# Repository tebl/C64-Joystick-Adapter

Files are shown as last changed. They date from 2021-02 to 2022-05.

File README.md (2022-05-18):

# C64 Joystick to USB

As with around 90% of my projects, it all somehow leads back to the Commodore 64 though sometimes even going quite beyond them as well (see [build options](#1-build-options) for these). In this case the idea was to put together a simple adapter so that I could use my Atari-style joysticks, vintage or otherwise, with modern systems over USB (including Raspberry Pi, The64 and the regular ones such as MS Windows 10).

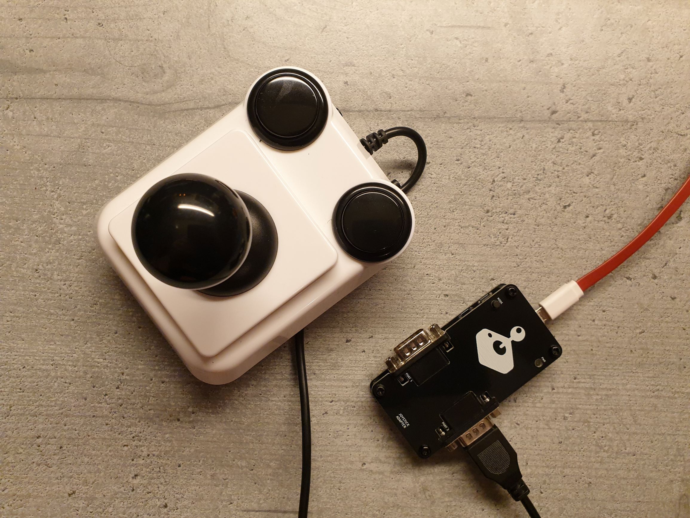
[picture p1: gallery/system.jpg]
System picture


The [JoyConverter](https://github.com/tebl/C64-Joystick-Adapter/tree/main/software/arduino/JoyConverter) firmware also supports paddles, these are mapped to the X and Y position in addition to registering a fire button for each of them (this is because a single port can hold two paddles, so with two ports we could potentially have up to four paddles). This is the mode mentioned in **settings.h**, you can enter paddle mode by holding down the mode button when powering on the unit (hold it down until the LED blinks).

One rather irritating problem with the C64 was that various games expected that your joystick is inserted into different joystick ports. For that reason I've added a bit of logic to the firmware to solve this, pushing the **mode** button will swap the active port so that you don't need to swap the cables or deal with this in the emulator settings separately. It was irritating enough on the physical machine as well, so that bit can certainly be said to have been perfectly emulated as well (on a physical Commodore 64, a different solution is the [C64 Joystick Switcher](https://github.com/tebl/C64-Joystick-Switcher)).

# 1> Build options
As already hinted at, the PCB design has been designed so that you have a few alternatives as to how you want to build up the PCB as well as the firmware options that are available to you. Given that there are some differences in the components used, make sure that you have a read through of the following sections before commiting to either of them. Note that on the The64 you will only have access to one of the ports, but at least you won't have to use the original joystick.

# 1.1> C64 Joystick Adapter
This is the version of the adapter that has been described so far, it requires **all** of the components listed in the [BOM](#-bom) and allows you to use up to two Atari-style joysticks or paddles on a modern system with USB-adapters. On the back of the PCB there are a four solder jumpers that need to be soldered so that pins **1-2** are bridged (marked Atari) - pin 1 is indicated by a square pad.

This build supports the following firmware alternatives:

- [JoyConverter](https://github.com/tebl/C64-Joystick-Adapter/tree/main/software/arduino/JoyConverter)

# 1.2> Sega Gamepad Adapter
Uses the same PCB as the *C64 Joystick Adapter*, but instead of allowing you to plug in Atari-style joysticks - this version instead allows you to use Sega Master System and Sega Mega Drive (Sega Genesis in North America) controllers. It is constructed in mainly the same way, except that you should **not** install resistors R1-R4 and then link the four solder jumpers across pins **2-3** (marked Sega) - pin 1 is indicated by a square pad.

This build supports the follwing firmware alternatives:

- [GenesisMachine](https://github.com/tebl/C64-Joystick-Adapter/tree/main/software/arduino/GenesisMachine)
- [The64Genesis](https://github.com/tebl/C64-Joystick-Adapter/tree/main/software/arduino/The64Genesis)

# 2> Building the adapter
I'm not going to go into great detail on this point as there is not much that can go wrong when soldering together this unit, just ensure that you have tools of at least moderate quality and you should not have much problems with it. That usually means a temperature-controlled soldering iron, some solder that isn't the kind used to weld pipes (the electronics version) and a table that isn't considered flammable. First things first though, is actually getting the parts - check the [BOM](#3-bom)-section below for a complete list as to what goes where.

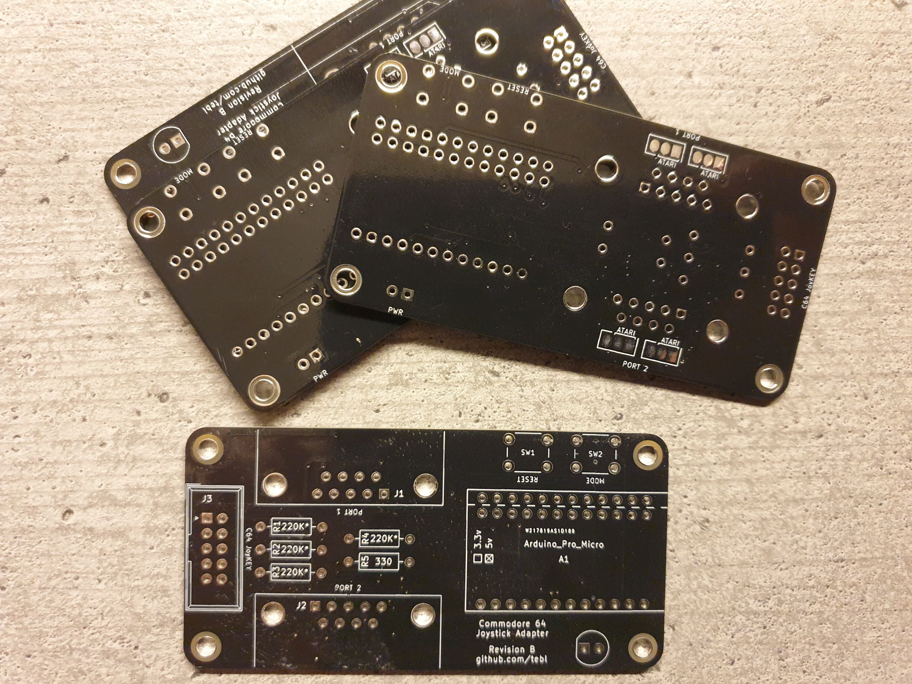
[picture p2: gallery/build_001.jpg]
Build 001


Note that [build options](#1-build-options) describes different ways of assembling the board, the pictures in this section have been taken when building a Sega Gamepad adapter - for this reason the jumpers are shown with this taken into account.

Everything ready to go? Then start your soldering iron, wait until sufficiently hot without getting distracted by the TV and start with the smallest of the components - the resistors (R1-R4 not installed with Sega controllers). Work your way up the size-scale from that point until you've populated everything, or at least populated the components you have an interest in having there (depending on build options).

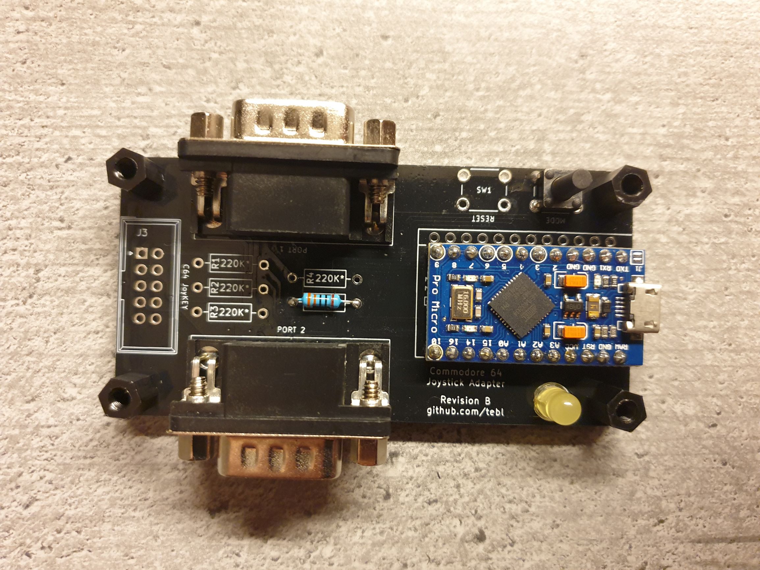
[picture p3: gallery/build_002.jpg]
Build 002


The last bit to solder in is usually the Arduino Pro Micro, you'll note that one side of the PCB footprint will have two sets of pins next to each other - this is to account for the two most common size variations of the Arduino Pro being sold. Solder the jumpers on the underside according to the build options you want.

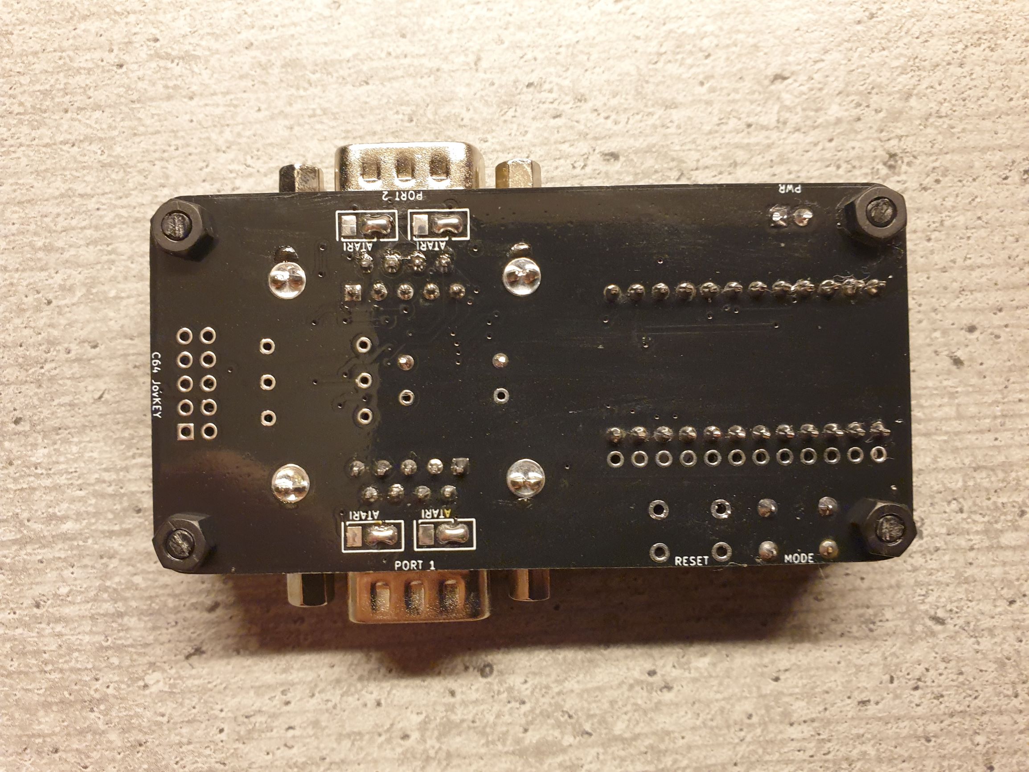
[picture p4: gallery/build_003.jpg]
Build 003


The last finishing touches is adding the faceplate, this has been made so that it is reversible and you'll show the side that matches the build. 8mm nylon standoffs hex standoffs are mounted on the device using the M3 nylon nuts on the underside (snip off the parts of the screw that are too long). Screw the faceplate into place using the screws from the front.

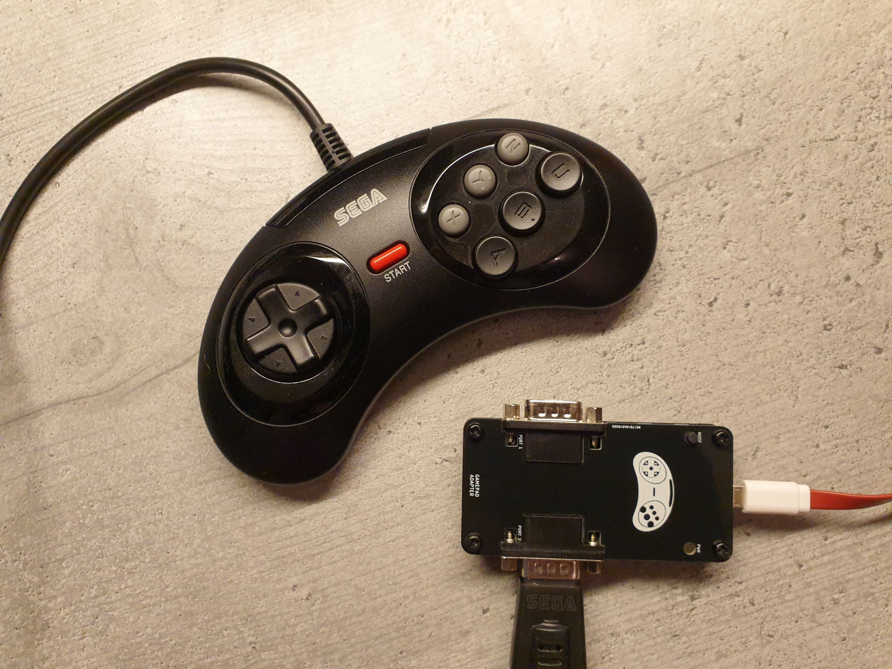
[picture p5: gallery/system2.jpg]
Build 004


# 2.1> Installing the firmware
Installing the firmware is mostly just opening up the Arduino sketch found within the software directory of this project, in case you're wondering - the reason for the elaborate folder structure is because I'm using PlatformIO as my development environment. It is recommended to have a read-through of the [build options](#1-build-options) in order to determine which firmware you are going to use with the device, in most cases however it'll be easiest to use *Arduino Studio* when compiling and flashing the sketch onto the Arduino (the The64 firmware selections also requires some modifications, see the documentation for those separately).

For the most part there are only two separate libraries that you will need to install manually. The library is called [ArduinoJoystickLibrary](https://github.com/MHeironimus/ArduinoJoystickLibrary), you'll have to download and install that one according to the  [installation-instructions](https://github.com/MHeironimus/ArduinoJoystickLibrary#installation-instructions) provided by the author. Essentially this means downloading the zip-file, then installing it using *Sketch --> Include library --> Add .ZIP library*. The second library is installed the same way, it is the [SegaController](https://github.com/jonthysell/SegaController) by Jon Thysell.

Finally you'll need to ensure that you have the correct board type selected for your Arduino Pro Micro. If you can't find the one shown in the image below, you might need to select something that is functionally the same or install the board definitions I used - instructions for doing this is available on the [sparkfun](https://learn.sparkfun.com/tutorials/pro-micro--fio-v3-hookup-guide/all)-article that was also mentioned in section [2.3](#23-in-case-of-trouble). Selecting the wrong one might make the board stop responding, fixing this is explained in the same article - usually by pressing the reset button twice and flashing the sketch to the device within 8 seconds (with the correct board type selected).

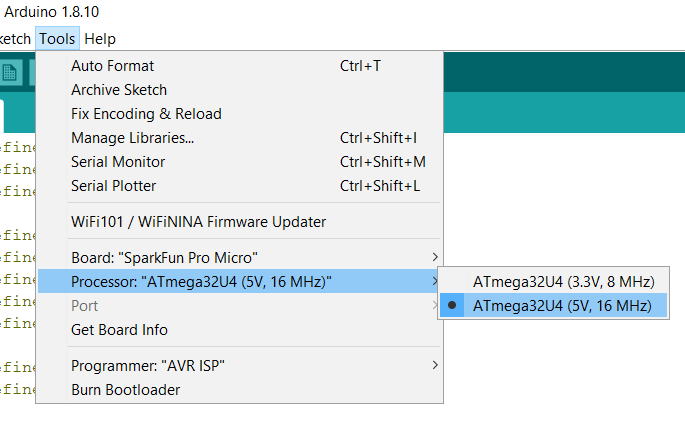
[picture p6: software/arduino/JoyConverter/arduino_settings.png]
Board selection


**NB!** The The64 Mini/Maxi requires that a different boards definition is used, the addition of this is described in details in the documentation for the [firmware](https://github.com/tebl/C64-Joystick-Adapter/tree/main/software/arduino/The64Genesis). With the relevant section added to your *boards.txt*, the board selection should look like what is shown below. This is not required when using the adapter with other systems such as MS Windows, Raspberry Pi-based systems etc.

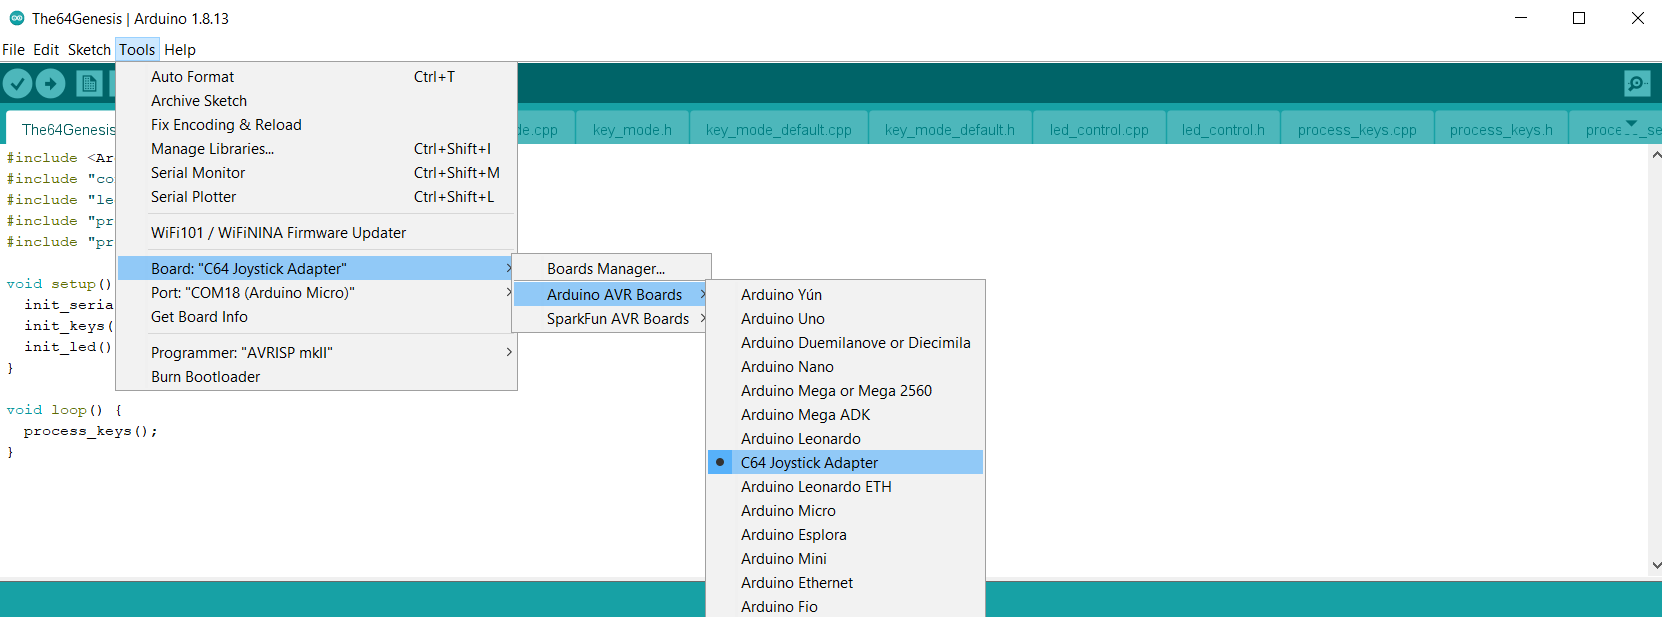
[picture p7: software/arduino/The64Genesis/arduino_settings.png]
The64 board selection


# 2.2> Testing it out
Actually testing it out in practice depends on the operating system running on the machine you're using it on, but if it's anything other than MS Windows 10 or Mac OS I'll just assume that you know what you're doing. Can't help you with the Mac OS unless someone gifts me a brand new Mac for this purpose, so for now - I'll just describe things from a Windows-based perspective.

The operating system (*Windows* was the assumption if you're still here) will see the adapter as two separate joysticks, no matter if anything is plugged into them - this is just the way they work. For an overview just hit the Windows-button (still *Windows*, unfortunately) and start typing in something like *Set up USB game controllers* and start that - you should see both of them, double-click one and you'll be able to test it all out (four directions, one button).

When it comes to emulators I've tried out Vice for Windows, here you'll need to select and assign each joystick to a port - save settings and that should be it. Remember the irritation that came with the Commodore 64 the joystick to be in different ports with different games, it's still there so keep that in mind.

I also tried out the WinAPE emulator (emulate the Amstrad CPC line of computers), and as far as I can tell it works right out of the box. Yay!

**NB!** It's already been mentioned, but check out the details for the firmware you are using. Most of these have an alternative mode, this is accessed by holding down the *MODE* button when plugging in the controller - realease the button when you see a flashing to confirm that it is using the alternative mode. When using [JoyConverter](https://github.com/tebl/C64-Joystick-Adapter/tree/main/software/arduino/JoyConverter) this allows you to use paddles, in [GenesisMachine](https://github.com/tebl/C64-Joystick-Adapter/tree/main/software/arduino/GenesisMachine) this instead converts a 6-button Sega controller into a 3-button Turbo controller.

# 2.3> In case of trouble
There are not many components on this board, but if you get into trouble there is usually a way to work logically through the circuit in order to pinpoint where the fault is; is the Arduino working, or is there just one part of the circuit that does not appear to work?

One problem might simply be that the Arduino is faulty -  they are produced at minimal cost, so it happens - try if a simple blink sketch work on it first. If you can't get anything to install on it, including the blink sketch - there's a pretty good troubleshooting article on the [sparkfun](https://learn.sparkfun.com/tutorials/pro-micro--fio-v3-hookup-guide/all) (note that you'll most likely need the reset switch installed on the PCB).

For everything that has already been mentioned, and the things I've probably forgotten to include - you'll need to check out the [schematic](https://github.com/tebl/C64-Joystick-Adapter/tree/main/documentation/schematic) for this project.

# 3> BOM
If you want to build a C64 Joystick Adapter that converts standard Atari-style joysticks into USB joysticks, then this is mainly the list of all the parts that you'd need for it. Most you should be able to get from your friendly neighbourhood electronics store, but I don't have any of those - so consider this a list of search tips for ebay, AliExpress, banggood or any similar site. Any parts listed in parenthesis might strictly not be needed for basic functionality for a single joystick, but if you're ordering stuff you might as well just build the whole thing.

| Reference | Item | Count | Order  |
| --- | --- | ----- | --- |
| Adapter (PCB) | Fabricate using Gerber files | 1 | [PCBWay](https://www.pcbway.com/project/shareproject/C64_Joystick_Adapter.html) |
| Faceplate (PCB) ** | Fabricate using Gerber files | (1)| [PCBWay](https://www.pcbway.com/project/shareproject/C64_Joystick_Adapter__Faceplate_.html) |
| A1 | Arduino Pro Micro | 1 | |
| D1 | 5mm LED | (1)| |
| J1,J2 | Male DB9 right-angle connector |  1 (1)| |
| R1-R4 | 220k Ohm resistor | (4)| |
| R5 | 330 Ohm resistor | (1)| |
| SW1 * | 6x6mm momentary button | (1)| |
| SW2 | 6x6x9mm momentary button | (1)| |
| ** | M3 nylon nut | (4)| |
| ** | M3x8mm nylon hex standoff | (4)| |
| ** | M3x6mm nylon screw | (4)| |

*) If you don't encounter any problems flashing the firmware onto the Arduino Pro Micro, I recommend not soldering in the Arduino *reset* button so you're not accidentally pressing it when frantically looking for the mode button instead.

**) These components are for the additional faceplate. Strictly not necessary, but keeps the  whole setup looking as stylish as it can be. The faceplate is reversible, so install it in the orientation to reflect the PCB build (Atari joystick or Sega gamepad).

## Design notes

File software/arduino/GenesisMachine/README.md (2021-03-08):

# GenesisMachine

This firmware was developed in order to use various Sega controllers with the *C64 Joystick Adapter* PCB, you can use the adapter with both 3 and 6 button *Sega Mega Drive* (*Sega Genesis* in North America) controllers as well as the Sega Master System gamepads. The differences between this and the Atari-style PCB is mainly that you do **not** install resistors R1-R4, the jumpers on the underside must also be set to the Sega position (pins 2-3). The firmware can be used with most modern systems, but note that if you want to use the adapter with a The64 Mini or Maxi you'll instead require the [The64Genesis](https://github.com/tebl/C64-Joystick-Adapter/tree/main/software/arduino/The64Genesis) firmware.


Jumpers

The usual mode of operation allows you to use all buttons on a 6-button controller, if the auto fire functionality has been enabled in the settings - then the controller *MODE* button will be used when toggling auto fire on/off (hold *MODE*, press the button to activate the function for and then release *MODE* in order to use this function reliably. The default controller layout is shown below.

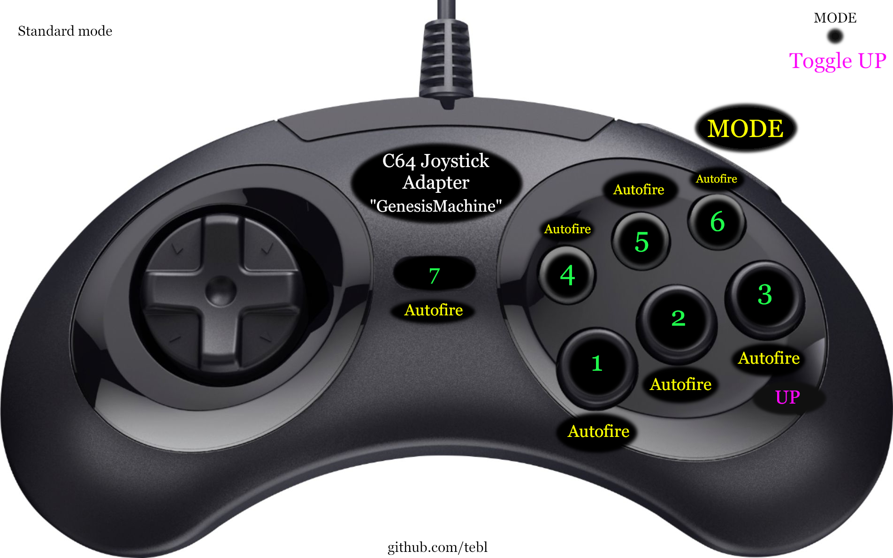
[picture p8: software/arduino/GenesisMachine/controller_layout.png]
Default 6-button layout


As with the original JoyConverter firmware for Atari-style joysticks, GenesisMachine also has an alternate mode of operation that is enabled by holding down *MODE* on the **device** (not the one on the controller). The LED will flash to show that you've successfully set it to the alternate mode. In the alternate mode, a 6-button controller will function as a 3-button turbo controller (XYZ is now used for the turbo function). As with the other firmware, you can also use autofire here though you can only enable it for the ABC buttons (again, hold *MODE* on the controller and press the button to toggle function on/off - then realease *MODE*). The alternate mode controller layout is shown below.

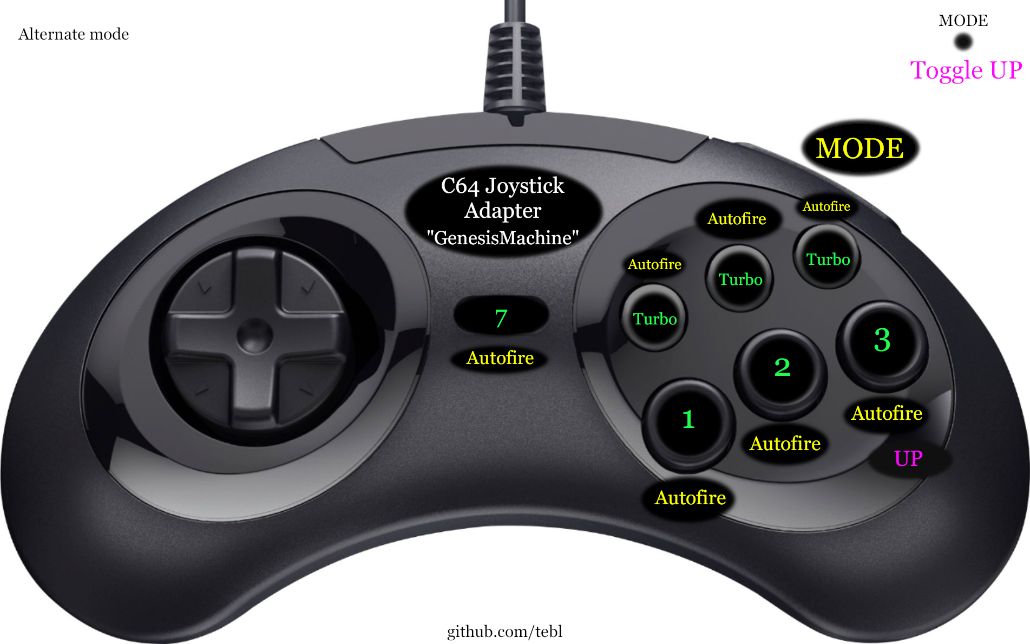
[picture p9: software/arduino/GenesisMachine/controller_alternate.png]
3-button turbo layout


At this point you'll be wondering what the *MODE* button on the device does - well, it remaps the C button to the UP direction (disabling D-pad UP). This should make things a lot easier when using the adapter and controller combination on with games originally made with joystick in mind, such as platformers on C64 and Amiga that required you to press UP to jump). This is the same in either of the primary or alternate mode.

### Settings
The Arduino sketch have some configurable options, you'll need to edit the file named **settings.h**. Have a read through the comments to see if there is anything you want to customize to your liking, lines without a value attached to them are disabled by commenting the line.

Given the example below, you would enable the autofire functionality by removing the two slashes (//) in front of *"#define ENABLE_AUTO_FIRE"*. The other values you just need to change the values, in this particular case - a lower value means a faster autofire or turbo fire (referred to as *rapid fire* here) response. Note that the software on the other end will have a hard time to follow if this is set too low, but feel free to experiment until you find what feels good for you and the games you play.
```
//#define ENABLE_AUTO_FIRE
#define AUTO_FIRE_PERIOD_ON 80
#define AUTO_FIRE_PERIOD_OFF 80
#define RAPID_FIRE_PERIOD_ON 70
#define RAPID_FIRE_PERIOD_OFF 70
```

Note that you can configure the adapter to always be in the alternate mode, or just skip the button selection logic and always use the default layout. This behaviour can be selected by uncommenting either of the two following lines.

```
//#define FORCE_PRIMARY
//#define FORCE_ALTERNATE
```

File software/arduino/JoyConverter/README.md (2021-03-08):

# JoyConverter
This was the original firmware for the C64 Joystick Adapter, it allows you to use all of the original Commodore 64 controllers on a modern computer over USB (including most Raspberry Pi-based options). Out of the box it supports the additonal fire button on the joysticks that came with the Commodore 64GS console - although I shouldn't have to mention it, this means a controller wired for active high on this pin (anything else, like the Sega Mega Drive or Sega Master System gamepads would sooner or later kill the SID chip on an original system).

System picture

Emulators, like the original system, have the rather irritating problem that various games would either require a joystick in port 1 or port 2 - forcing you to move the cable all the time. For this reason, JoyConverter swaps the ports around when **MODE** on the device is pushed.

The firmware has an alternate mode that allows you to use paddles, this maps each of the two paddles to the X and Y directions. You can access the alternate mode by holding down **MODE** when plugging in the adapter, after around a second it will blink the LED to know that it is in this mode.

## Settings
The Arduino sketch have some configurable options, you'll need to edit the file named **settings.h**. Note that you'll have to recompile and upload the new version of the firmware every time you make changes to it. If you want the device to always be in the alternate mode, for use with paddles, you can enable **FORCE_ALTERNATE** (remove the two slashes in front of it).
```
//#define FORCE_PRIMARY
//#define FORCE_ALTERNATE
```

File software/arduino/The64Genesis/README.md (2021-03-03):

# The64Genesis

I picked up a The64 Mini on a whim and a sale, more than likely because someone in the shop had tried it out at some point and come to some conclusions regarding the quality of the thing. The machine itself is super-cute with its less than functional keyboard and breadbox-y shape, but the reviews really did not go far enough in explaining exactly how dreadful the controller really is. Commodore 64 games are hard enough, even with a sensible joystick so I needed something else.

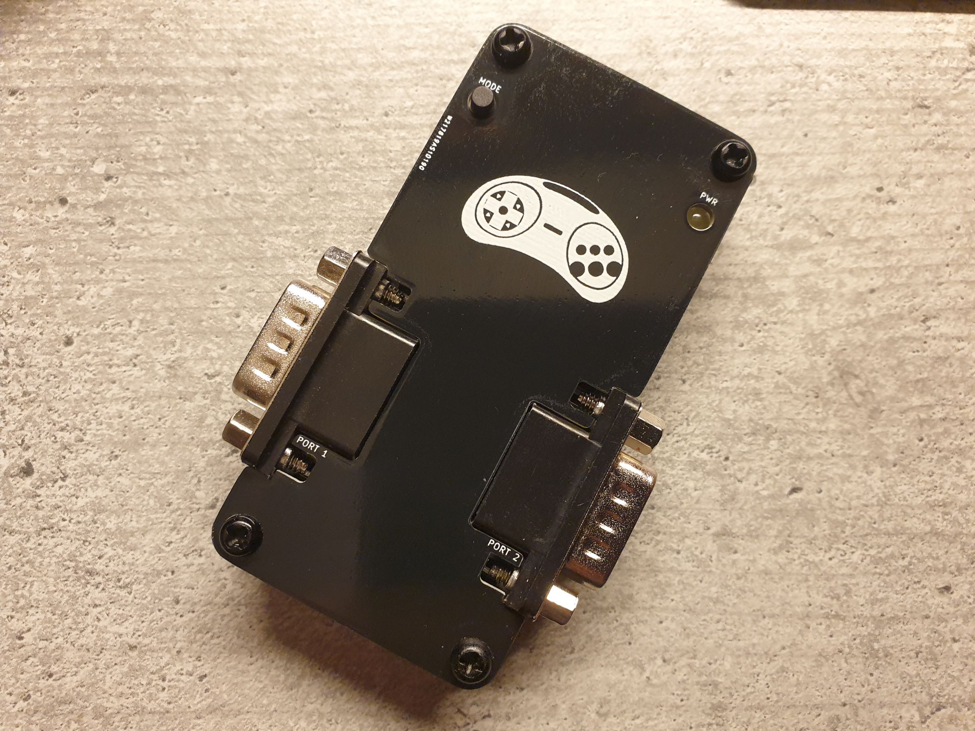
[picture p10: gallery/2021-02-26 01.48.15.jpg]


I started out with the GenesisMachine firmware I made earlier, then discovered that none of the keys worked since the Mini have some sort of controller whitelist and well-behaved Arduino Pro Micro solutions simply arent't on the list - so I did the next best thing; copy the relevant bits from people who actually know what they are doing. In this case relief was found in the form of an [article](https://www.tsb.space/projects/c64-mini-arcade2usb-converter/) written by TSB, it links further to his [github](https://github.com/iamtsb/arcade2usb-converter)-repository.

# Controller layout
The resulting adapter have buttons laid out according to the illustration below, the yellow buttons are accessed by holding down the MODE-button that should be available on regular 6-button controllers. When activating any of the functions, be sure to hold down the MODE button as it detects a press by the release of a button - trying to push both at the same time will probably not perform as expected. Autofire can be enabled and disabled for the two fire buttons individually, a quick function by holding MODE and pushing B can be used to quickly disable both of them at the time (so that you don't have to remember or guess at which ones are currently active).

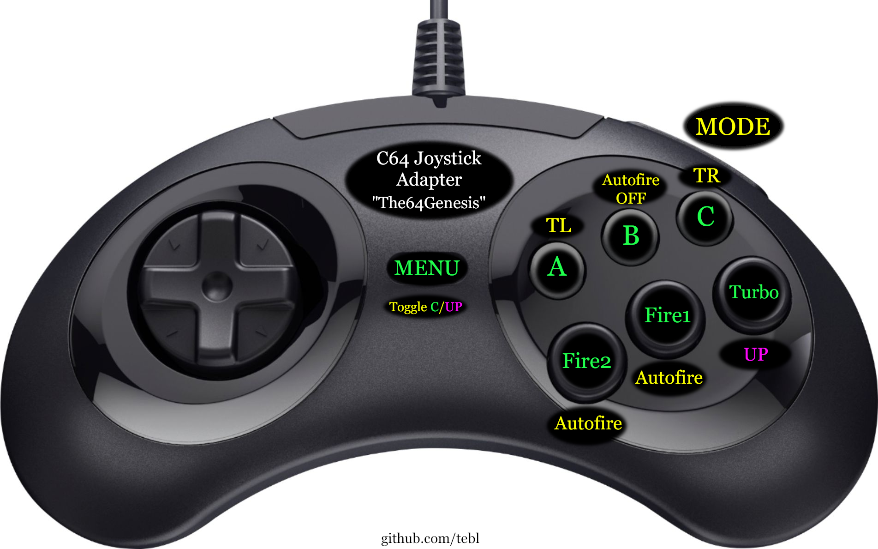
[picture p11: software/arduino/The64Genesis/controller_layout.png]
Controller layout


Playing Commodore 64 games on a gamepad isn't always easy though, especially the precision needed in a lot of platformers and a few racing games will be harder to do perform on a gamepad. For this reason, most of the Mega Drive/Genesis adapters for the real Commodore 64 comes with the ability to use the C button instead of the UP button on the gamepad. Holding MODE and pushing MENU, alternatively pushing MODE on the C64 Joystick Adapter, enables this mode of operation. Note that this replaces the turbo functionality, D-pad UP will be deactivated to avoid accidental presses.

# Buiding The64Genesis
The instructions for building has been provided in the main project, for the most part this includes installing at least controller port 2 and soldering the jumpers for Sega pinouts. Switch and LED (with 330 ohm resistor) can be considered optional if you don't have them on hand, but it is recommended as it makes things easier. The location of the soldered jumpers can be seen below.

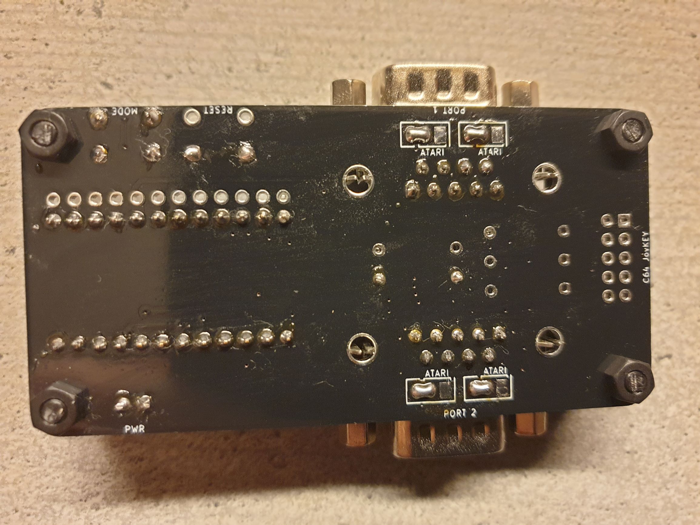
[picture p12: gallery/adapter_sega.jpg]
Sega Jumpers


The following sections mainly deal with installing the firmware on a suitable Arduino Pro Micro clone.

## Firmware installation
The firmware is supplied in the form of an Arduino-sketch, you'll find it under The64Genesis subfolder. The following subsections goes through setting up additional libraries needed, changing the Arduino board identifier needed and how to change any settings (should you want to do so).

### Installing libraries
Given that we need Arduino IDE to compile and upload the firmware, more on this later, we'll need to install an extra library. Thankfully I'm lazy when it comes to adopting new libraries, so there's only one that needs to be installed - [ArduinoJostickLibrary](https://github.com/MHeironimus/ArduinoJoystickLibrary). You can follow the documentation on the page for the exact details, but in short it is: download [library](https://github.com/MHeironimus/ArduinoJoystickLibrary/archive/master.zip) in zip-format, install it from the Arduino IDE  by going to *Tools --> Include library --> Add .ZIP Library*.

### Changing Arduino board identifier
As the already mentioned article describess, the solution works by changing the HID identifier for the Arduino Pro Micro so that it matches up to a different controller that is already in the mentioned whitelist. This is done by adding the contents of the supplied boards.txt file into the one used by the Arduino software, on my system the complete path to this file is *C:\Program Files (x86)\Arduino\hardware\arduino\avr\boards.txt* - you'll probably have to edit as an administrator. While the code was developed using PlatformIO, you'll need to compile and upload the code using Arduino IDE in order to make this work (select *C64 Joystick Adapter* from the list of boards instead of Arduino Leonardo/Arduino Pro Micro).

Open up the *The64Genesis.ino* sketch found in the folder with the same name, if all things are going according to plan - you'll see a new option in the list of boards (as shown below). Compile and upload as normal.

Board setup

### Settings
The Arduino sketch have some configurable options, you'll need to edit the file named **settings.h**. Have a read through the comments to see if there is anything you want to customize to your liking, lines without a value attached to them are disabled by commenting the line.

Given the example below, you would enable the autofire functionality by removing the two slashes (//) in front of *"#define ENABLE_AUTO_FIRE"*. The other values you just need to change the values, in this particular case - a lower value means a faster autofire or turbo fire (referred to as *rapid fire* here) response. Note that the software on the other end will have a hard time to follow if this is set too low, but feel free to experiment until you find what feels good for you and the games you play.
```
//#define ENABLE_AUTO_FIRE
#define AUTO_FIRE_PERIOD_ON 80
#define AUTO_FIRE_PERIOD_OFF 80
#define RAPID_FIRE_PERIOD_ON 70
#define RAPID_FIRE_PERIOD_OFF 70
```

**NB!** Note that you'll have to recompile and upload the new version of the firmware every time you make changes to it. There's no magic wireless version, unfortunately. I might add a way of storing the settings in the Arduino EEPROM, but I'm not sure the world needs another adapter with 30-page listing of incantations needed to change a setting - you have the code so you can change what you want.

# Design caveats
I don't know of a way that the mini can support more than one controller this way, so with this firmware only Port 2 will be active. Comment out the SWAP_PORTS line in *settings.h* if you want to plug your Sega Mega Drive controller into port 1 instead. The firmware will function as normal with only a 3-button Sega Master System controller, but in order to navigate all the features of The64 Mini you'll want a 6-button controller.

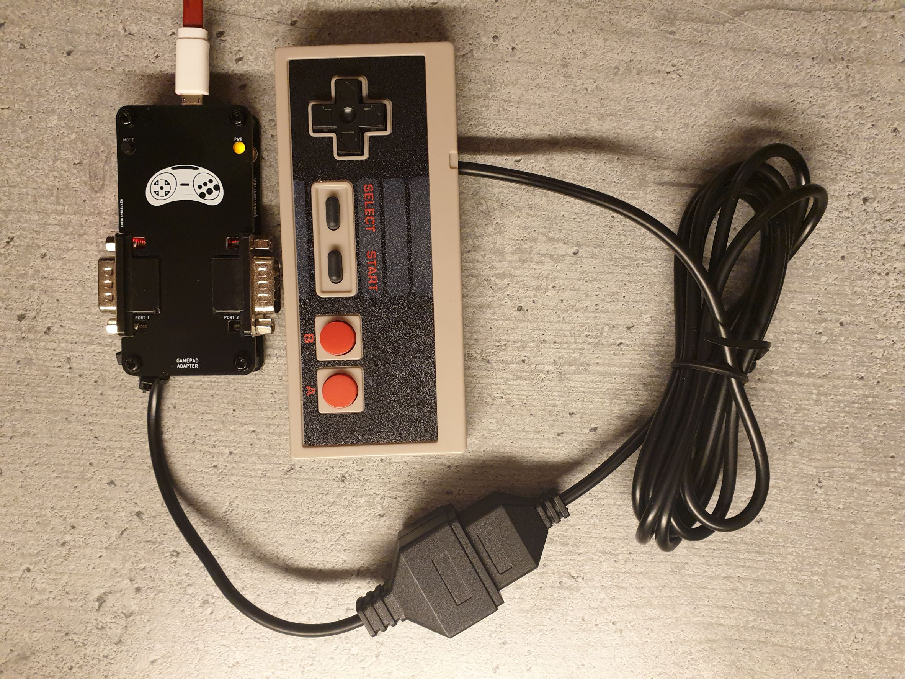
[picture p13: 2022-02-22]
gallery/2022-02-22 23.05.25.jpg

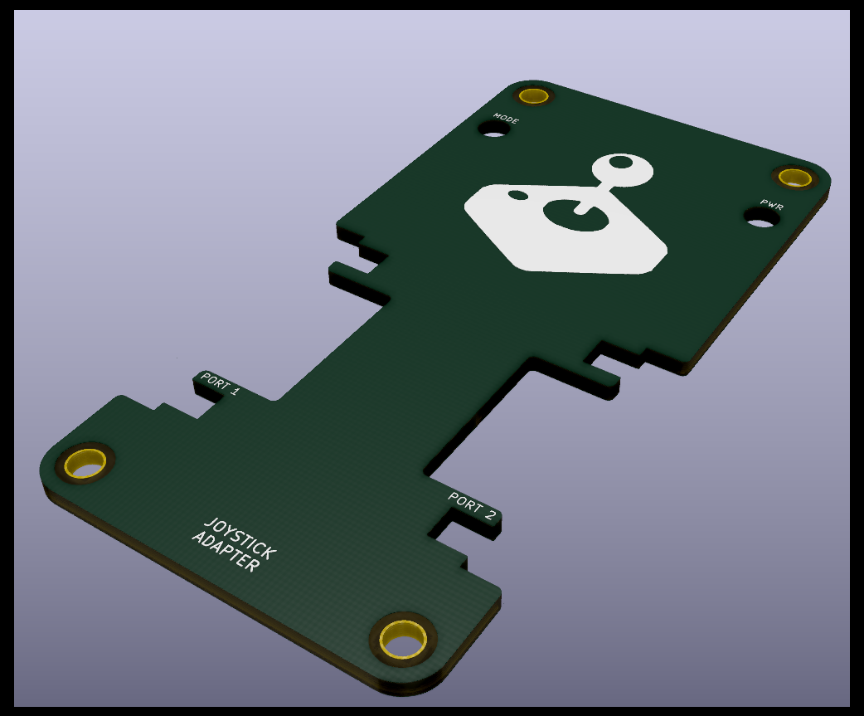
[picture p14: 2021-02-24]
gallery/C64 Joystick Faceplate A1.png

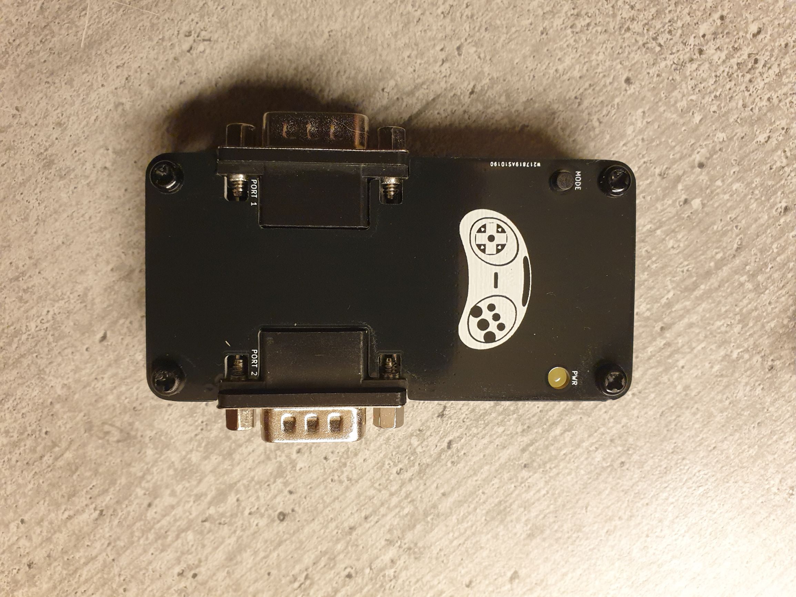
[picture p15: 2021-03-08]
gallery/2021-02-26 01.49.08.jpg

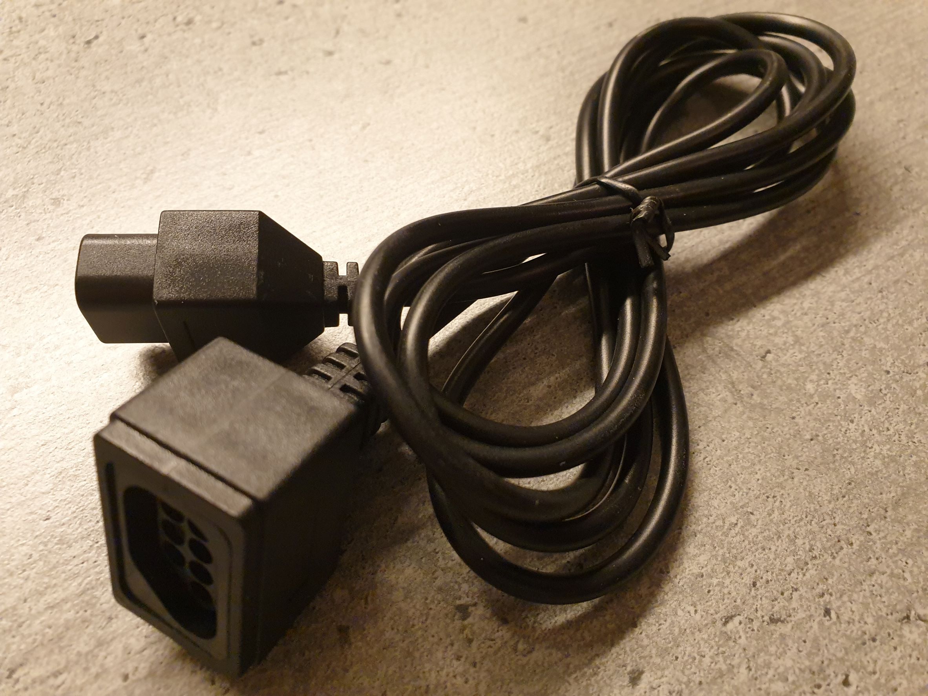
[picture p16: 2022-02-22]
gallery/2022-02-21 23.11.21.jpg

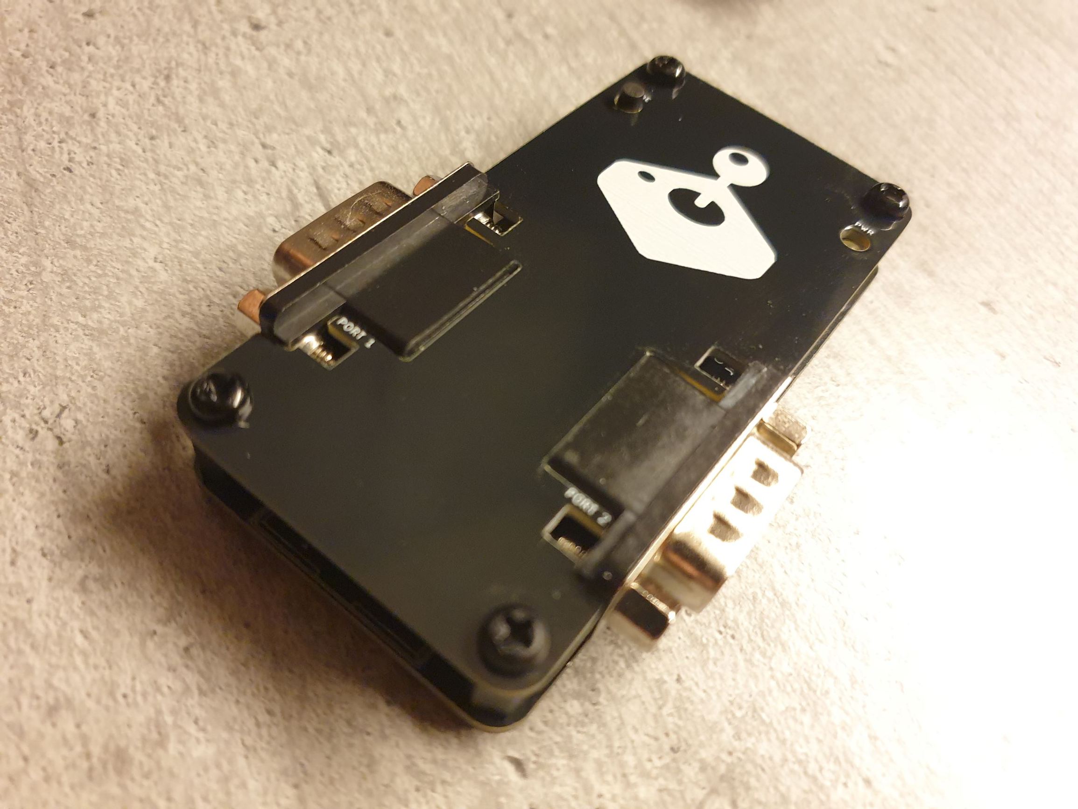
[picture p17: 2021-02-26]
gallery/2021-02-26 01.58.57.jpg

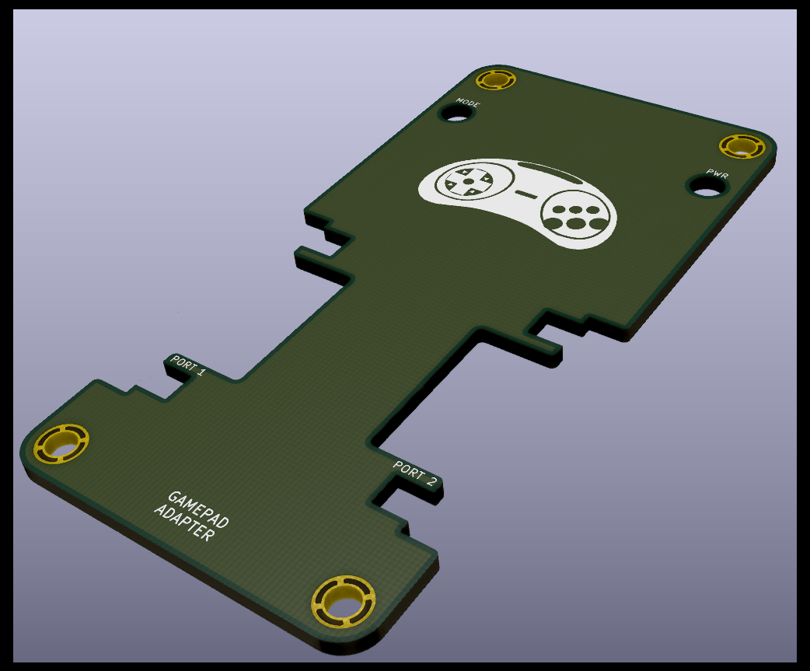
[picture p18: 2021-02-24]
gallery/C64 Joystick Faceplate A1B.png

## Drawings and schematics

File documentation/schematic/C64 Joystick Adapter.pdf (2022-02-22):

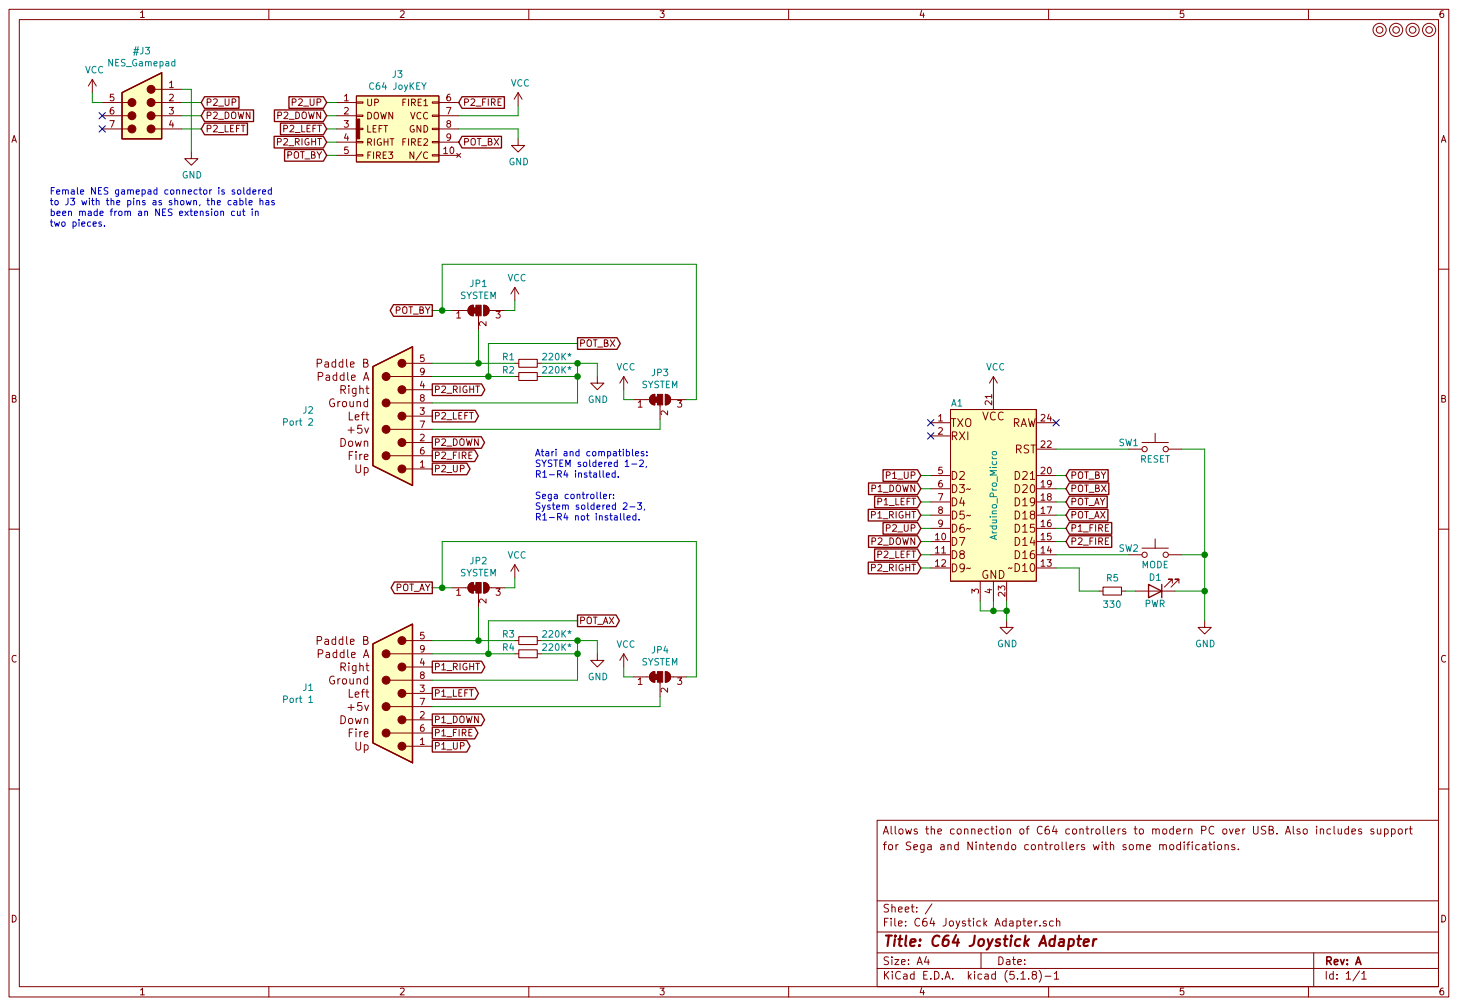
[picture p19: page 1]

Female NES gamepad connector is soldered
to J3 with the pins as shown, the cable has been made from an NES extension cut in

Atari and compatibles: SYSTEM soldered 1-2, R1-R4 installed. Sega controller:

System soldered 2-3, R1-R4 not installed.

for Sega and Nintendo controllers with some modifications.

File: C64 Joystick Adapter.sch Sheet: /
Id: 1/1 Title: C64 Joystick Adapter

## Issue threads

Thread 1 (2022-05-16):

Problem with BOM

FairFight14, 2022-05-16:
Hi,

You've put "Female DB9 right-angle connector" - I believe this should be "Male DB9 right-angle connector"?

tebl, 2022-05-18:
Yes, you're right. Thanks for pointing this out 😀

man. 16. mai 2022, 18:21 skrev FairFight14 ***@***.***>:

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

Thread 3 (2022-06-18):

JoyConverter: Port 2 Firebutton not working under MiSTer

AlecVoid, 2022-06-18:
Hi,

I build serveral adapters and tested them as fully working under Windows 10. Then I tried the adapter on my MiSTer setup and while the first port works flawlessly, the second port ("Port 2" on the silkscreen; the port on the side on which the LED sits) does have a non working firebutton.

I tested differend adapters and differend joysticks and its the same problem with all of them. Might be a MiSTer problem, might be something with the JoyConverter C64 Joystick Adapter.

Any help?

Regars,
AlecVoid

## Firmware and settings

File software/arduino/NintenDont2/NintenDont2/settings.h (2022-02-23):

#include "constants.h"

/*
 * Settings
 */
#define APP_TITLE "NintenDon't II"
#define APP_VERSION "0.1"

#define LED_PWR_MAX 64                // Maximum brightness
#define LED_SHUTOFF 3000              // Time after boot when fade starts
#define LED_FADE_SPEED 250            // Delay between LED fade steps
#define LED_FADE_DELAY 1000           // Time before fading starts
#define LED_STEP 4                    // Change per step when fading
#define LED_FLASH_DELAY 100           // Delay between blink steps
#define BOOT_MODE_THRESHOLD 1000      // Time needed before alternate mode
#define DEBOUNCE_DELAY 10             // Debounce delay for keys

/* When uncommented this allows the PWR light to show joystick activity,
 * it'll grow brighter with movement and fade over time.
 */
#define PWR_ACTIVITY
#define PWR_ACTIVITY_MIN 8            // Defines a minimum activity LED level,
                                      // uncomment to allow fading out completely.
#define LINK_AUTOFIRE_PWR             // PWR LED flickers in sync with autofire

/* Specifies the minimum hold time of the magic key-combination to enable
 * alternate mode. BOOT_DELAY specifies the length of the pause given the
 * user to release the key combination.
 */
#define BOOT_MODE_THRESHOLD 1000
#define BOOT_DELAY 1000

/* Specify ALTERNATE_MODE to customize which mode is used when the mode button
 * on the device is held during powerup. At the moment there is probably no
 * alternative so leave it at this setting - or you could swap the values
 * around if you prefer. See FORCE_PRIMARY / FORCE_ALTERNATE to skip the
 * selection process on bootup.
 */
#define PRIMARY_MODE KEY_MODE_DEFAULT
// #define ALTERNATE_MODE KEY_MODE_DEFAULT

/* Uncomment one of these lines to force a specific mode, meaning that the
 * the startup timer allowing you to hold in the mode button is removed.
 */
#define FORCE_PRIMARY
//#define FORCE_ALTERNATE

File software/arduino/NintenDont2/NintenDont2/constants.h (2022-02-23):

#ifndef _CONSTANTS_H
#define _CONSTANTS_H

/* 
 * Pin definitions, these identify the digital pin numbers used by the Arduino.
 * The number in the comment behind the line is the pin number on the 
 * IDC-connector. I would have wanted to put wire colours here, but the
 * extension cables are pretty random in that regards so you'll need a
 * multimeter to figure those out.
 */
#define PIN_CLK 6       /*       J3 IDC pin 1 */
#define PIN_LATCH 7     /*       J3 IDC pin 2 */
#define PIN_DATA 8      /*       J3 IDC pin 3 */
                        /* VCC - J3 IDC pin 7 */
                        /* GND - J3 IDC pin 8 */
#define PIN_SHIFT_DELAY 6

#define PIN_PWR 10
#define PIN_MODE 16

/* 
 * Definitions
 */
#define LED_OFF 0
#define KEY_MODE_DEFAULT 0
#define AXIS_RANGE 1
#define AXIS_NEUTRAL 0

/* These are the button IDs seen on computer */
#define SC_KEY_B 0
#define SC_KEY_A 1
#define SC_KEY_SELECT 2
#define SC_KEY_START 3
#define SC_KEY_MODE 4

/* These button IDs are used when referring to the byte data coming from the
 * NES controller.
 */
#define KEY_A 0
#define KEY_B 1
#define KEY_SELECT 2
#define KEY_START 3
#define KEY_UP 4
#define KEY_DOWN 5
#define KEY_LEFT 6
#define KEY_RIGHT 7
#define KEY_COUNT 8
#endif

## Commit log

2021-01-12 Basic schematic
    [C64 JoyAdapter.kicad_pcb, C64 JoyAdapter.sch]
2021-01-12 Layout done
    [C64 JoyAdapter.kicad_pcb, C64 JoyAdapter.sch]
2021-01-12 ... and the rest of the files.
    [C64 JoyAdapter-B_Cu.gbl, C64 JoyAdapter-B_Mask.gbs, C64 JoyAdapter-B_Paste.gbp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]
2021-01-13 Renamed main module name
    [C64 Joystick Adapter-B_Cu.gbl, C64 Joystick Adapter-B_Mask.gbs, C64 Joystick Adapter-B_Paste.gbp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]
2021-02-01 Add board setup
2021-02-01 Tweaked so that LED doesn't fade off (configurable)
    [key_mode_default.cpp, settings.h]
2021-02-02 Switch joystick ports
2021-02-02 Switch paddle ports
2021-02-02 Show paddle value on LED when changing
2021-02-05 Added second fire button (as found on C64 GS controller)
2021-02-05 Changed SW1 footprint
    [C64 Joystick Adapter-B_Cu.gbl, C64 Joystick Adapter-B_Mask.gbs, C64 Joystick Adapter-B_Paste.gbp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]
2021-02-05 Blank faceplates and placement tweaks to main module
    [C64 Joystick Adapter-B_Cu.gbl, C64 Joystick Adapter-B_Mask.gbs, C64 Joystick Adapter-B_Paste.gbp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]
2021-02-06 Added faceplate a1
    [C64 Joystick Faceplate A1-B_Cu.gbl, C64 Joystick Faceplate A1-B_Mask.gbs, C64 Joystick Faceplate A1-B_Paste.gbp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]
2021-02-07 Added jumpers for SEGA pinout
    [C64 Joystick Adapter-B_Cu.gbl, C64 Joystick Adapter-B_Mask.gbs, C64 Joystick Adapter-B_Paste.gbp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]
2021-02-07 Changed one faceplate side to gamepad
    [C64 Joystick Faceplate A1-B_Cu.gbl, C64 Joystick Faceplate A1-B_Mask.gbs, C64 Joystick Faceplate A1-B_Paste.gbp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]
2021-02-24 Adjusted faceplate cutout to fit better
    [C64 Joystick Faceplate A1-B_Cu.gbl, C64 Joystick Faceplate A1-B_Mask.gbs, C64 Joystick Faceplate A1-B_Paste.gbp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]
2021-02-24 Increase mode and LED hole size
    [C64 Joystick Faceplate A1-B_Cu.gbl, C64 Joystick Faceplate A1-B_Mask.gbs, C64 Joystick Faceplate A1-B_Paste.gbp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]
2021-02-24 Silkscreen tweaks
    [C64 Joystick Adapter-B_Cu.gbl, C64 Joystick Adapter-B_Mask.gbs, C64 Joystick Adapter-B_Paste.gbp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]
2021-02-24 Read adapter mode button to swap ports
    [constants.h, key_mode_default.cpp, settings.h]
2021-02-24 Added alternate mode, converting a 6 six button controller into a 3 button turbo gamepad instead.
2021-02-25 Renamed current autofire implementation to turbo mode
2021-02-25 Moved a trace
    [C64 Joystick Adapter.kicad_pcb]
2021-03-01 Mode button now switches so that C is up (disabling normal function and D-pad up)
2021-03-02 Switch case fell out
2021-03-03 Can use all the buttons
2021-03-03 Report all 10 buttons
2021-03-03 Added rapid fire button
2021-03-08 Update gerber files
    [C64 Joystick Adapter-B_Cu.gbl, C64 Joystick Adapter-B_Mask.gbs, C64 Joystick Adapter-B_Paste.gbp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]
2022-02-22 Firmware to read NES controller
    [C64 Joystick Adapter.sch]
2022-02-22 Disable RX/TX LED
